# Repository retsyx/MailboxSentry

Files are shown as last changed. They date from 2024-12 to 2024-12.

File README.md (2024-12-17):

# Mailbox Sentry

Mailbox Mail Delivery Notification for HomeKit. Be notified when the mailman delivers your mail by attaching an accelerometer to the mailbox lid.

This project requires two ESP32 devices. The sensor element, in the mailbox, runs on a battery and sleeps most of the time. Sleeping is incompatible with HomeKit's requirement that WiFi devices always be powered. So a second ESP32 device is used as a wall powered hub that is always available on WiFi. The sensor communicates with the hub using Espressif's ESP-NOW mechanism. ESP-NOW bootstrapping is done manually, by editing the code.

Using available development boards, this is a fairly large sensor. See the included STL files to get an idea of the size of the sensor using the recommended hardware. In principal, it should be straightforward to design a very compact custom board with an ESP32 and a Bosch BMA400 accelerometer on board.

## Requirements

* Two Espressif ESP32 devices, one for the sensor element, and one for the hub element. The sensor element should ideally have a charging circuit to allow charging the LiPo that will power the sensor. [The SparkFun Qwiic Pocket Development Board](https://www.sparkfun.com/products/22925) has an onboard charger, and is easy to interface with a suitable accelerometer.
* Bosch BMA400 accelerometer. The [SparkFun BMA400 Qwicc board](https://www.sparkfun.com/products/21207) interfaces easily with the SparkFun Qwiic Pocket.
* LiPo Battery. If using the linked SparkFun board, use a battery with a JST PH 2.0mm connector. Ensure that the polarity of the battery leads match the polarity of the board connector. The SparkFun Qwicc Pocket's connector polarity is the opposite of most hobby LiPos sold. Battery connector pins can be easily pried out with a utility knife to reverse their position in the connector. [This LiPo](https://www.amazon.com/dp/B0CNLNZFQL) battery works well after the leads have been reversed.
* [Arduino IDE](https://www.arduino.cc/en/software)

## Building

This project was designed around the recommended SparkFun hardware. It is possible to use any ESP32 and BMA400 devices. But you will likely need to change the pin assignments for I2C and battery charge level to match the hardware you use. You will also likely need to tweak the battery charge level calculation in the hub to match the hardware you are using in the sensor.

### Prep

* Install [Arduino IDE](https://www.arduino.cc/en/software)
* In the Arduino IDE, Select 'Tools' -> 'Manage Libraries'
    * Install the (SparkFun) BMA400 library.
    * Install the HomeSpan library.
* In the Arduino IDE, Select 'Tools' -> 'Board' -> 'Board Manager'
    * Install support for the ESP32 boards you are using (Use the Espressif ESP32 library if using the recommended board).

### Hub

* Open, compile, and install the hub project onto an ESP32.
    * If there are compilation/upload failures because of space, select 'Tools' -> 'Partition Scheme', and select a partition scheme with a larger APP size (OTA is not supported so 'No OTA' is ok)
* Use the Arduino IDE's serial monitor and [HomeSpan's CLI](https://github.com/HomeSpan/HomeSpan/blob/master/docs/CLI.md) to configure the hub's WiFi, and add it to HomeKit.
* Write down the hub's MAC address reported in the serial monitor!

### Sensor

* Connect the BMA400 accelerometer's INT1 pin to the ESP32's GPIO 5 pin. If using different pins, make sure to modify the code to match.
* Open the sensor project.
* Find the MAC address string in the code `12:34:56:78:9A:BC`, and replace it with the hub's MAC address.
* Compile, and install the sensor project on an ESP32 with a BMA400 accelerometer.
    * If there are compilation/upload failures because of space, select 'Tools' -> 'Partition Scheme', and select a partition scheme with a larger APP size (OTA is not supported so 'No OTA' is ok)
* Write down the sensor's MAC address reported in the serial monitor!
* To reupload the sensor code onto an already running sensor; on the board, press and hold the `boot` button and press the `reset` button. Release both and the board will be ready for the upload. After upload, press the `reset` button again to start the code.
* To save a bit on power consumption, change the code to disable serial logging by defining `ENABLE_SERIAL` to `0`. Recompile, and upload.

### Hub Redux

* In the hub code, find the MAC address string `12:34:56:78:9A:BC`, and replace it with the sensor's MAC address.
* Recompile, and reinstall the code onto the hub.

## Test

With both the sensor and hub running, ensure that moving the accelerometer triggers a notification to HomeKit. The serial monitors may provide useful debug messages, if it doesn't immediately work. If the initial test works, try the same with the sensor operating solely on battery power (disconnect it from your computer).

## Packaging

If the linked hardware is used, the provided STL files are suitable for 3D printing case components for the sensor element (ESP32 board, and BMA400 board). Print without supports.

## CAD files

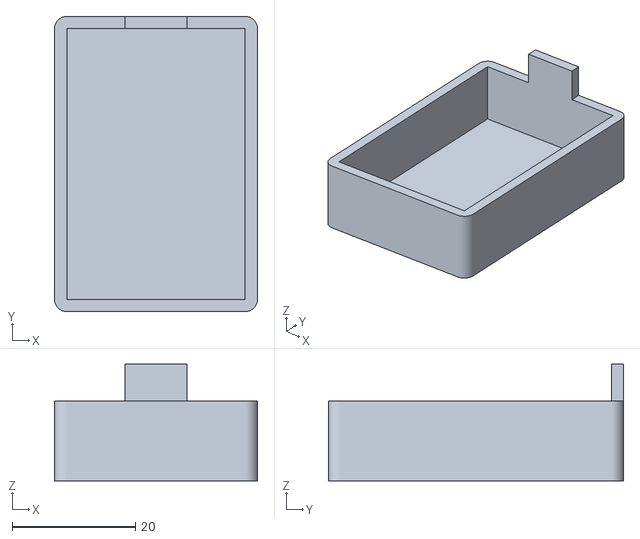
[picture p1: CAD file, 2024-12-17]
cases/Sensor - Main Bottom.stl
33.0 x 48.0 x 19.0

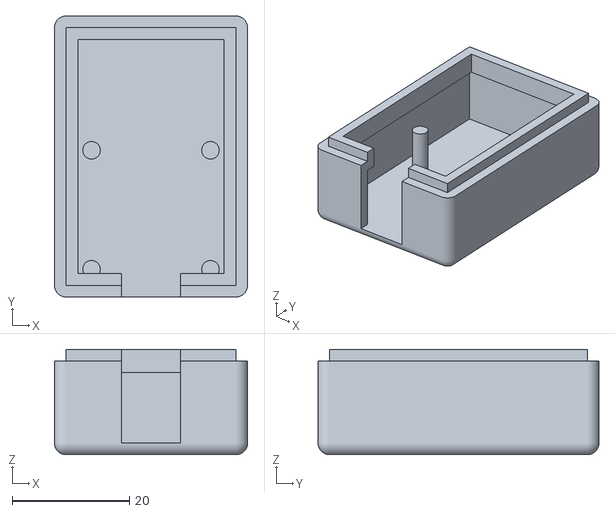
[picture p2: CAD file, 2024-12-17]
cases/Sensor - Main Top.stl
33.0 x 48.0 x 18.0

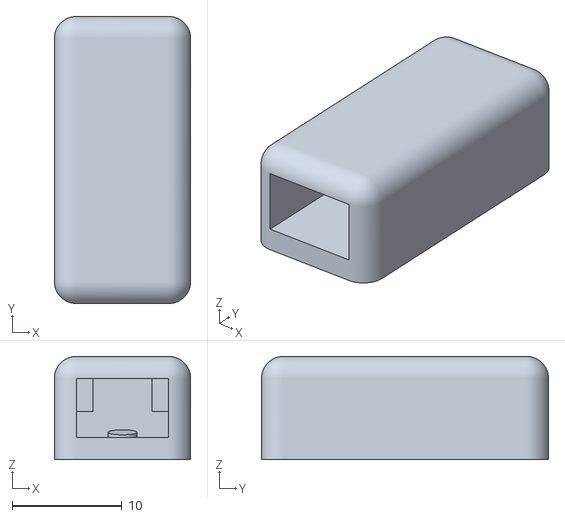
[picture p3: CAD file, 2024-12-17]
cases/Sensor - Sensor Case.stl
12.4 x 26.1 x 9.40

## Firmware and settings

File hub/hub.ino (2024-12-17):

#include "HomeSpan.h"

#define HOUR_TO_MIN(T) ((T)*60)
#define MIN_TO_SEC(T) ((T)*60)
#define SEC_TO_MSEC(T) ((T) * 1000)
#define MIN_TO_MSEC(T) (SEC_TO_MSEC(MIN_TO_SEC(T)))
#define HOUR_TO_MSEC(T) MIN_TO_MSEC(HOUR_TO_MIN(T))

const int control_pin = 2;
const int status_led_pin = 23;

struct msg_t {
  uint16_t battery_level;
  bool motion_detected;
};

volatile bool have_msg;
msg_t msg;
SpanPoint * remote;

struct RemoteMotionSensor : Service::MotionSensor {
  const char * name;
  SpanCharacteristic * motion_detected;
  SpanCharacteristic * fault;

  RemoteMotionSensor(const char * name) : Service::MotionSensor() {
    this->name = name;
    motion_detected = new Characteristic::MotionDetected();
    fault = new Characteristic::StatusFault(1);
  }

  void loop() {
    if (have_msg) {
      motion_detected->setVal(msg.motion_detected);
      fault->setVal(0);
      Serial.printf("Sensor %s update: %d\n", name, msg.motion_detected);
    } else if (motion_detected->getVal() && remote->time() > SEC_TO_MSEC(10)) {
      motion_detected->setVal(false);
    } else if (remote->time() > HOUR_TO_MSEC(6) && !fault->getVal()) {
      fault->setVal(1);
      Serial.printf("Sensor %s update: FAULT\n", name);
    }
  }
};

struct RemoteBatteryService : Service::BatteryService {
  SpanCharacteristic * battery_level;
  SpanCharacteristic * status_low_battery;
  SpanCharacteristic * charging_state;

  RemoteBatteryService() : Service::BatteryService() {
    battery_level = new Characteristic::BatteryLevel(100);
    status_low_battery = new Characteristic::StatusLowBattery(0);
    charging_state = new Characteristic::ChargingState(0);
  }

  void loop() {
    if (have_msg) {
      // Battery levels.
      // The sensor measures a value of 2000 when the battery is fully charged at 4.2V
      // This corresponds to roughly 476 [units] / V
      // Battery will be considered fully discharged at 3.5V = 1666 [units]
      // Mapping to 100%, where 3.5V is 0%, and 4.2V is 100% yields:
      // P = 100 * (U - 1666) / (2000 - 1666) = (U - 1666) * 100 / 334

      uint16_t level = msg.battery_level;
      bool is_low = false;
      float v = level / 476.0f;
      if (level < 1666) {
        level = 1666;
      } else if (level > 2000) {
        level = 2000;
      }
      uint16_t p = (level - 1666) * 100 / 334;
      if (p < 20) {
        is_low = true;
      }
      battery_level->setVal(p);
      status_low_battery->setVal(is_low);
      Serial.printf("Battery level %d%% (%.2fV) is_low %d\n", p, v, is_low);
    }
  }
};

void setup() {
  btStop();
  WiFi.setHostname("MailboxSentry");

  // Start serial
  Serial.begin(115200);

  Serial.print("Start CPU frequency: ");
  Serial.print(getCpuFrequencyMhz());
  Serial.println(" MHz");

  setCpuFrequencyMhz(80);

  Serial.print("Updated CPU frequency: ");
  Serial.print(getCpuFrequencyMhz());
  Serial.println(" MHz");

  //homeSpan.setControlPin(control_pin);
  //homeSpan.setStatusPin(status_led_pin);
  homeSpan.setApSSID("Sentry");
  homeSpan.setApPassword("sentry");
  homeSpan.enableAutoStartAP();

  homeSpan.begin(Category::Sensors, "Mailbox Sentry", "MailboxSentry");

  new SpanAccessory();
    new Service::AccessoryInformation();
      new Characteristic::Identify();
      new Characteristic::Manufacturer("github.com/retsyx");
      new Characteristic::SerialNumber("1");
      new Characteristic::Model("Mailbox Sentry");
      new Characteristic::FirmwareRevision("1.0");
    new RemoteBatteryService();
    new RemoteMotionSensor("Device 1");

  const char * macAddress = "12:34:56:78:9A:BC";
  remote = new SpanPoint(macAddress, 0, sizeof(msg_t));
}

void loop() {
  have_msg = remote->get(&msg);
  if (have_msg) {
    Serial.printf("Have message %d %d\n", msg.motion_detected, msg.battery_level);
  }
  homeSpan.poll();
}

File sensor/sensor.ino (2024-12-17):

#include <Wire.h>
#include "SparkFun_BMA400_Arduino_Library.h"
#include "HomeSpan.h"

#define HOUR_TO_MIN(T) ((T)*60ull)
#define MIN_TO_SEC(T) ((T)*60ull)
#define SEC_TO_MSEC(T) ((T) * 1000ull)
#define MIN_TO_MSEC(T) (SEC_TO_MSEC(MIN_TO_SEC(T)))
#define HOUR_TO_MSEC(T) MIN_TO_MSEC(HOUR_TO_MIN(T))
#define SEC_TO_USEC(T) ((T)*1000ull*1000ull)
#define MIN_TO_USEC(T) (SEC_TO_USEC(MIN_TO_SEC(T)))
#define HOUR_TO_USEC(T) MIN_TO_USEC(HOUR_TO_MIN(T))

struct msg_t {
  uint16_t battery_level;
  bool motion_detected;
};

// I2C address selection
uint8_t i2c_addr = BMA400_I2C_ADDRESS_DEFAULT;  // 0x14

// Pin used for interrupt detection (must be RTC GPIO for wakeup)
const int interrupt_pin = 5;

const int battery_pin = 1;

// Define I2C pins (modify if using different pins)
const int SDA_PIN = 6;
const int SCL_PIN = 7;

BMA400 accelerometer;

SpanPoint *hub;

esp_sleep_wakeup_cause_t wakeup_reason;

#define ENABLE_SERIAL 1

#if ENABLE_SERIAL

#define serial_begin() do { Serial.begin(115200); delay(1000); } while (false)
#define printf(...) Serial.printf(__VA_ARGS__)

#else

#define serial_begin()
#define printf(...)

#endif

void setup() {
  serial_begin();

  // Get the wakeup reason
  wakeup_reason = esp_sleep_get_wakeup_cause();

  // Start serial
  printf("MAC Address = %s\n", Network.macAddress().c_str());

  // Mac address of hub
  hub = new SpanPoint("12:34:56:78:9A:BC", sizeof(msg_t), 0);

  homeSpan.setLogLevel(1);

  // Initialize the I2C library
  Wire.begin(SDA_PIN, SCL_PIN);

  // Check if sensor is connected and initialize
  while (accelerometer.beginI2C(i2c_addr) != BMA400_OK) {
    printf("Error: BMA400 not connected, check wiring and I2C address!\n");
    delay(1000);
  }

  printf("BMA400 connected!\n");

  msg_t msg = {};
  msg.battery_level = analogRead(battery_pin);
  printf("Battery level %d\n", msg.battery_level);

  if (wakeup_reason == ESP_SLEEP_WAKEUP_EXT1) {
    printf("Woke up due to ext1 interrupt!\n");
    msg.motion_detected = true;
  } else {
    msg.motion_detected = false;
    printf("Power on or other wakeup.\n");
  }

  bool success = send(msg);

  if (msg.motion_detected && success) {
    delay(SEC_TO_MSEC(5));
    msg.motion_detected = false;
    send(msg);
  }

  goto_sleep();
}

bool send(msg_t & msg) {
  bool success;
  int count = 0;
  while (count++ < 5) {
    success = hub->send(&msg);
    printf("Send(%d) msg %d %d %s\n", count, msg.motion_detected, msg.battery_level, success ? "Succeded" : "Failed");
    if (success) {
      return true;
    }
    delay(1000);
  }
  return false;
}

#define CHECK(A) do { int x; if (x = (A)) printf("Error %d "#A"\n", x); } while (false)

void goto_sleep() {
  // Configure wakeup interrupt
  bma400_wakeup_conf wakeupConfig = {
    .wakeup_ref_update = BMA400_UPDATE_ONE_TIME,
    .sample_count = BMA400_SAMPLE_COUNT_8,
    .wakeup_axes_en = BMA400_AXIS_XYZ_EN,
    .int_wkup_threshold = 4,
    .int_wkup_ref_x = 255,
    .int_wkup_ref_y = 255,
    .int_wkup_ref_z = 255,
    .int_chan = BMA400_INT_CHANNEL_1
  };
  CHECK(accelerometer.setWakeupInterrupt(&wakeupConfig));

  // Configure the INT1 pin to push/pull mode, active high
  CHECK(accelerometer.setInterruptPinMode(BMA400_INT_CHANNEL_1, BMA400_INT_PUSH_PULL_ACTIVE_1));

  // Enable auto wakeup interrupt condition
  CHECK(accelerometer.enableInterrupt(BMA400_AUTO_WAKEUP_EN, true));

  // Set up automatic transition to low power mode
  bma400_auto_lp_conf autoLPConfig = {
    .auto_low_power_trigger = BMA400_AUTO_LP_TIME_RESET_EN,
    .auto_lp_timeout_threshold = 400  // 1 second timeout
  };
  CHECK(accelerometer.setAutoLowPower(&autoLPConfig));

  // Configure generic interrupt to reset auto low power timer
  bma400_gen_int_conf config = {
    .gen_int_thres = 5,
    .gen_int_dur = 1,
    .axes_sel = BMA400_AXIS_XYZ_EN,
    .data_src = BMA400_DATA_SRC_ACCEL_FILT_2,
    .criterion_sel = BMA400_ACTIVITY_INT,
    .evaluate_axes = BMA400_ANY_AXES_INT,
    .ref_update = BMA400_UPDATE_EVERY_TIME,
    .hysteresis = BMA400_HYST_48_MG,
    .int_thres_ref_x = 0,
    .int_thres_ref_y = 0,
    .int_thres_ref_z = 512,
    .int_chan = BMA400_UNMAP_INT_PIN
  };
  CHECK(accelerometer.setGeneric2Interrupt(&config));

  // Enable generic 2 interrupt condition
  CHECK(accelerometer.enableInterrupt(BMA400_GEN2_INT_EN, true));

  CHECK(accelerometer.setMode(BMA400_MODE_LOW_POWER));

  // Configure the ESP32 to wake up when interruptPin goes high
  esp_sleep_enable_ext1_wakeup((1 << interrupt_pin), ESP_EXT1_WAKEUP_ANY_HIGH);

  esp_sleep_enable_timer_wakeup(HOUR_TO_USEC(3ull));

  // Prepare for deep sleep by configuring GPIOs
  // Disable I2C to prevent leakage currents
  Wire.end();

  // Set I2C pins to input with no pull-up/down
  pinMode(SDA_PIN, INPUT);
  pinMode(SCL_PIN, INPUT);

  // Disable internal pull-up/pull-down resistors
  gpio_pulldown_dis((gpio_num_t)SDA_PIN);
  gpio_pullup_dis((gpio_num_t)SDA_PIN);
  gpio_pulldown_dis((gpio_num_t)SCL_PIN);
  gpio_pullup_dis((gpio_num_t)SCL_PIN);

  printf("Entering deep sleep...\n");

  esp_deep_sleep_start();  // Enter deep sleep
}
